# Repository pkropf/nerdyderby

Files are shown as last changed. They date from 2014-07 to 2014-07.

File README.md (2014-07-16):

Nerdy Derby Race Track
======================

This instance of the Nerdy Derby Race Track is a derivative of the
Nerdy Derby project as found at http://nerdyderby.com. Their most
excellent work was an inspiration to creating this one.

As stated on the Nerdy Derby website, "The Nerdy Derby is a no-rules*
miniature car building and racing competition inspired by the Cub
Scouts' Pinewood Derby. With a larger, more undulating track and no
restrictions on the size of the cars or materials participants can
use, the Nerdy Derby rewards creativity, cleverness and ingenuity."

The work represented by these files is intended to help others create
their own tracks and may cause more harm than help. Verify, recheck
and then recheck again everything before you use these files.

Files
-----

The original design came in a reduced scale as a PDF file. The design
was re-implemented in Autodesk Inventor with _nd.iam_ being the
primary assembly file. The _nd-NUMBER.ipt_ and _nd-LETTER.ipt_
represent the individual inside and outside track segments as starting
with the finish line.

The _nd-NUMBER.dxf_ and _nd-LETTER.dxf_ files are the faces of track
segments needed by VCarve Pro to setup the tool path for a ShopBot
Alpha to cut the segments from 3/4" plywood.

The _nd-NUMBER*.crv_ and _nd-LETTER*.crv_ files are the VCarve Pro
files used to generate the _nd-NUMBER*.sbp_ and _nd-LETTER*.sbp_
ShopBot files.

The ShopBot files may or may not work for you. Ensure that you've
verified them before starting them on a ShopBot. If needed, there
should be enough detail in the other files to create the needed
ShopBot files for your installation.

The _track*.skp_ files were an early attempt to create the track
segments using SketchUp. But since Sketchup's circles and curves are
segmented lines, this effort was abandonded and Inventor was used
instead.

Build Time
----------

The curved segments for the track were cut out on a ShopBot Alpha
useing 3 pieces of 3/4" plywood. This work took approximately 8 hours
of ShopBot time.

The straight segments were cut out on a table saw using 2 pieces of
3/4" plywood along with the left over piece from the curvd
segments. This was approximately 4 hours of work.

Glue up of the segments took approximately 5 hours. First assembly
took an additional hour. Standing the track took another 2 hours.

There's another 2 or 3 hours used to buy supplies, transport
materials, etc.

The design work consumed on the order of 6 hours.

Notes
-----

  * Cutting the straight segments on a tablesaw saved ShopBot time but
    cost sanding time since the cuts were not a precise as would have
    been on the ShopBot.

  * The segments should have been numbered / lettered and a toolpath
    created to carve the numbers / letters into the segments on the
    ShopBot. By not doing this, some amount of time was used to just
    organize the segments so that the correct ones were glued
    together.

  * Don't forget to zero the z axis. The ShopBot doesn't know and will
    happily carve into your material and possibly break bits and
    parts.

  * In VCarve Pro, set up 2 tabs per piece, especially for longer pieces.

  * The default 1/8" tab is too shallow for plywood. Use 1/4" tabs.

  * Ensure that the tabs aren't being cut by a previous or following pass.

  * Make sure tabs aren't connected to other pieces that are cut out.

  * The ShopBot files were exported from VCarve Pro as Shopbot alpha w/ speed.

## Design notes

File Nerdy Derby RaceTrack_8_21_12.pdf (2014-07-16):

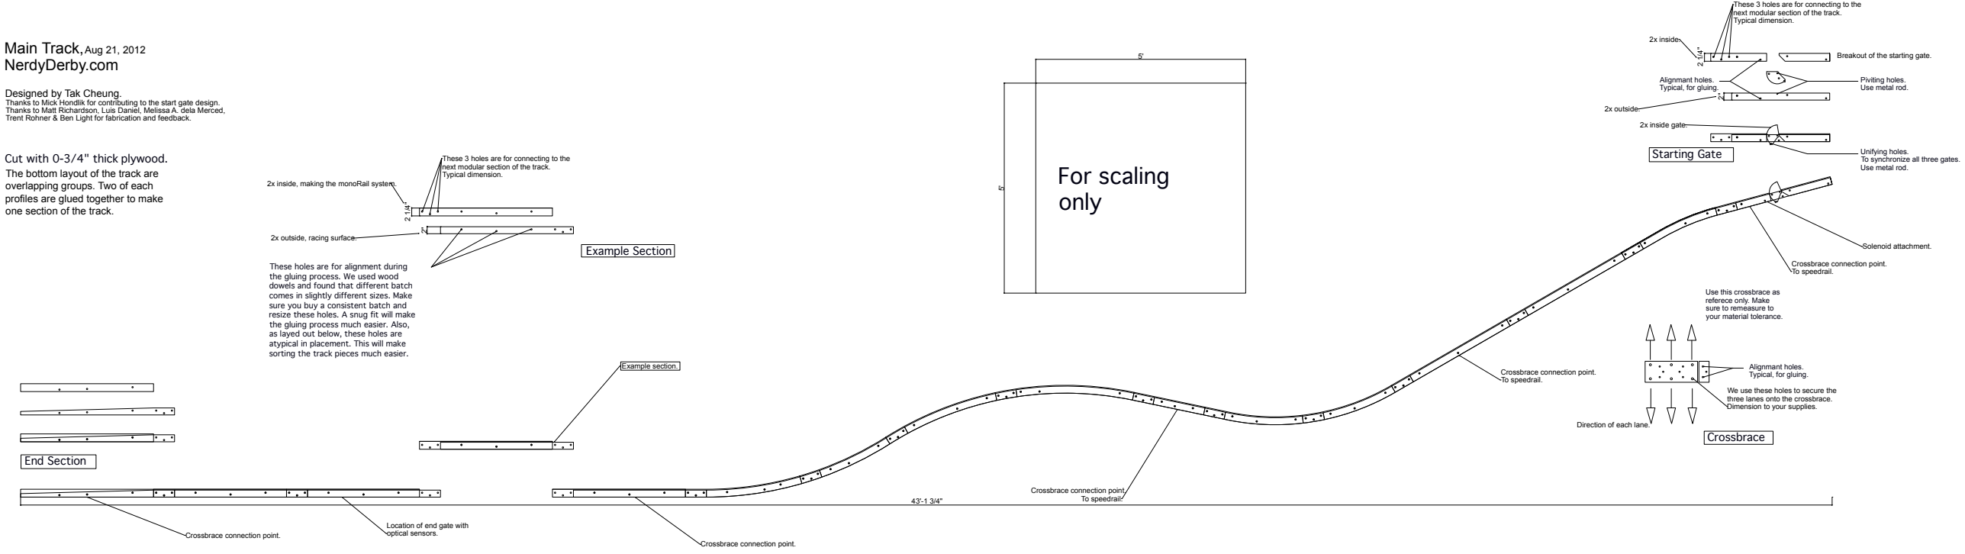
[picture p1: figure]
Main Track, Aug 21, 2012 NerdyDerby.com; Example section.; 2x inside, making the monoRail system.; 2x outside, racing surface.; These 3 holes are for connecting to the next modular section of the track. Typical dimension.; These holes are for alignment during the gluing process. We used wood dowels and found that different batch comes in slightly different sizes. Make sure you buy a consistent batch and the gluing process much easier. Also, as layed out below, these holes are atypical in placement. This will make sorting the track pieces much easier.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

## resize these holes. A snug fit will make

These 3 holes are for connecting to the

Thanks to Mick Hondlik for contributing to the start gate design. Thanks to Matt Richardson, Luis Daniel, Melissa A. dela Merced, Trent Rohner & Ben Light for fabrication and feedback.

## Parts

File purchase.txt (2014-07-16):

dowel for axels, 1 1/4"
balsa wood for body, 1 1/4 x 1 3/4 x 7

mcmaster $157.62

need

rasps?
graph paper

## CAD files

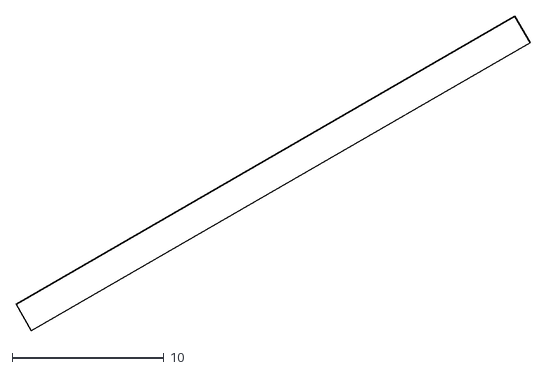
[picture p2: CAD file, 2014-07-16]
nd-n.dxf
33.9 x 20.7

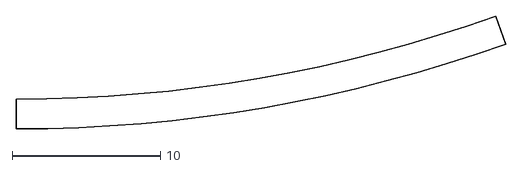
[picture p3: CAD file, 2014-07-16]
nd-f.dxf
33.0 x 7.61

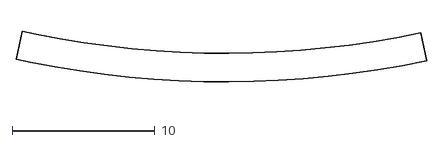
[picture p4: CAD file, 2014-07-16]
nd-k.dxf
28.7 x 4.04

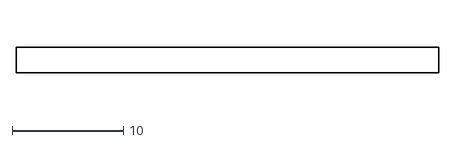
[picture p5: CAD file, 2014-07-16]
nd-5.dxf
38.0 x 2.25

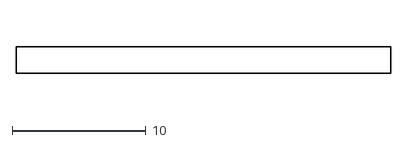
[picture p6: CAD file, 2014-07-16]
nd-p.dxf
28.0 x 2.00

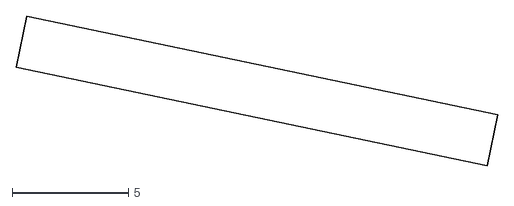
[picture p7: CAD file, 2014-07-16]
nd-10.dxf
20.8 x 6.44

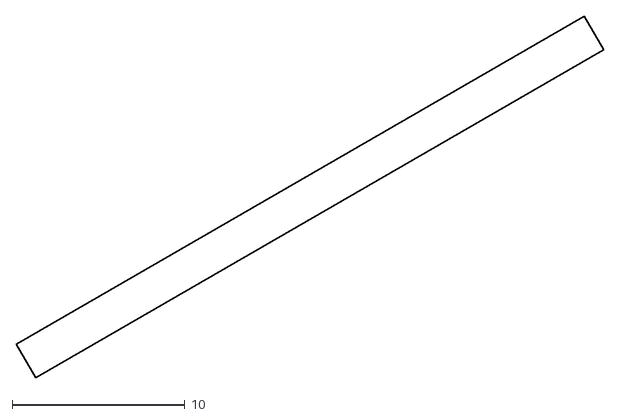
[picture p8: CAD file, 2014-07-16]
nd-14.dxf
34.0 x 20.9

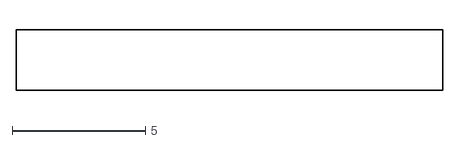
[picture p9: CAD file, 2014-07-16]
nd-16.dxf
16.0 x 2.25

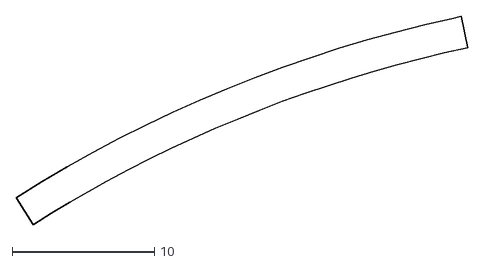
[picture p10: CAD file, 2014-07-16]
nd-8.dxf
31.8 x 14.6

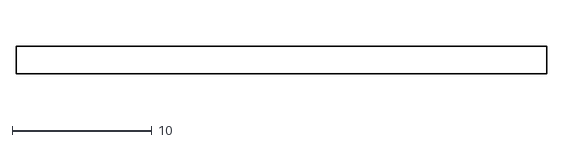
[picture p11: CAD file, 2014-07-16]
nd-b.dxf
38.0 x 2.00

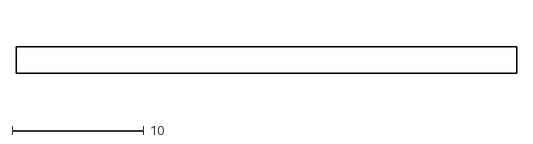
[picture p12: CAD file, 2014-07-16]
nd-d.dxf
38.0 x 2.00

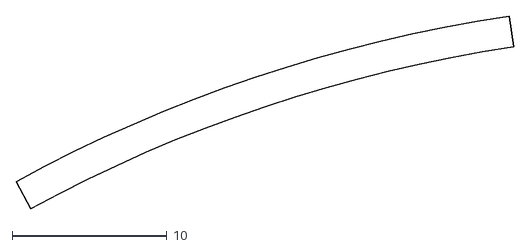
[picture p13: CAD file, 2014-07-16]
nd-h.dxf
32.1 x 12.4

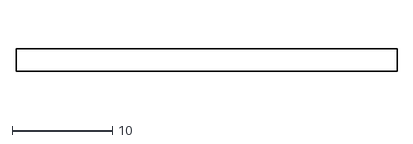
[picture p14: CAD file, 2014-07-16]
nd-2.dxf
38.0 x 2.25

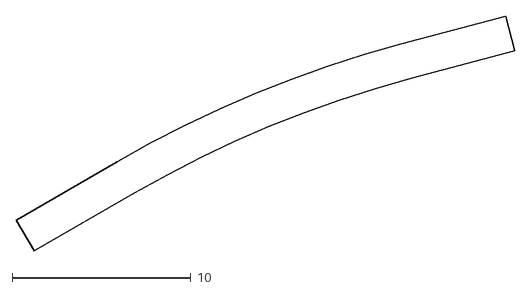
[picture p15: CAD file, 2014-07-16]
nd-o.dxf
27.9 x 13.1

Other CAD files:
Nerdy Derby RaceTrack_8_21_12.dwg
Nerdy Derby RaceTrack Pieces.dwg
nd-4.dxf
nd-11.dxf
nd-1.dxf
nd-1.ipt
nd-10.ipt
nd-10_MIR.ipt
nd-11.ipt
nd-11_MIR.ipt
nd-12.dxf
nd-12.ipt
nd-12_MIR.ipt
nd-13.dxf
nd-13.ipt
nd-13_MIR.ipt
nd-14.ipt
nd-14_MIR.ipt
nd-15.dxf
nd-15.ipt
nd-15_MIR.ipt
nd-16.ipt
nd-16_MIR.ipt
nd-17.dxf
nd-17.ipt
nd-17_MIR.ipt
nd-1_MIR.ipt
nd-2.ipt
nd-2_MIR.ipt
nd-3.dxf
nd-3.ipt
nd-3_MIR.ipt
nd-4.ipt
nd-4_MIR.ipt
nd-5.ipt
nd-5_MIR.ipt
nd-6.dxf
nd-6.ipt
nd-6_MIR.ipt
nd-7.dxf
nd-7.ipt
nd-7_MIR.ipt
nd-8.ipt
nd-8_MIR.ipt
nd-9.dxf
nd-9.ipt
nd-9_MIR.ipt
nd-a.dxf
nd-a.ipt
nd-a_MIR.ipt
nd-a_MIR1.ipt
nd-b.ipt
nd-b_MIR.ipt
nd-c.dxf
nd-c.ipt
nd-c_MIR.ipt
nd-d.ipt
nd-d_MIR.ipt
nd-e.dxf
nd-e.ipt
nd-e_MIR.ipt
nd-f.ipt
nd-f_MIR.ipt
nd-g.dxf
nd-g.ipt
nd-g_MIR.ipt
nd-gate.dxf
nd-gate.ipt
nd-h.ipt
nd-h_MIR.ipt
nd-i.dxf
nd-i.ipt
nd-i_MIR.ipt
nd-j.dxf
nd-j.ipt
nd-j_MIR.ipt
nd-k.ipt
nd-k_MIR.ipt
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

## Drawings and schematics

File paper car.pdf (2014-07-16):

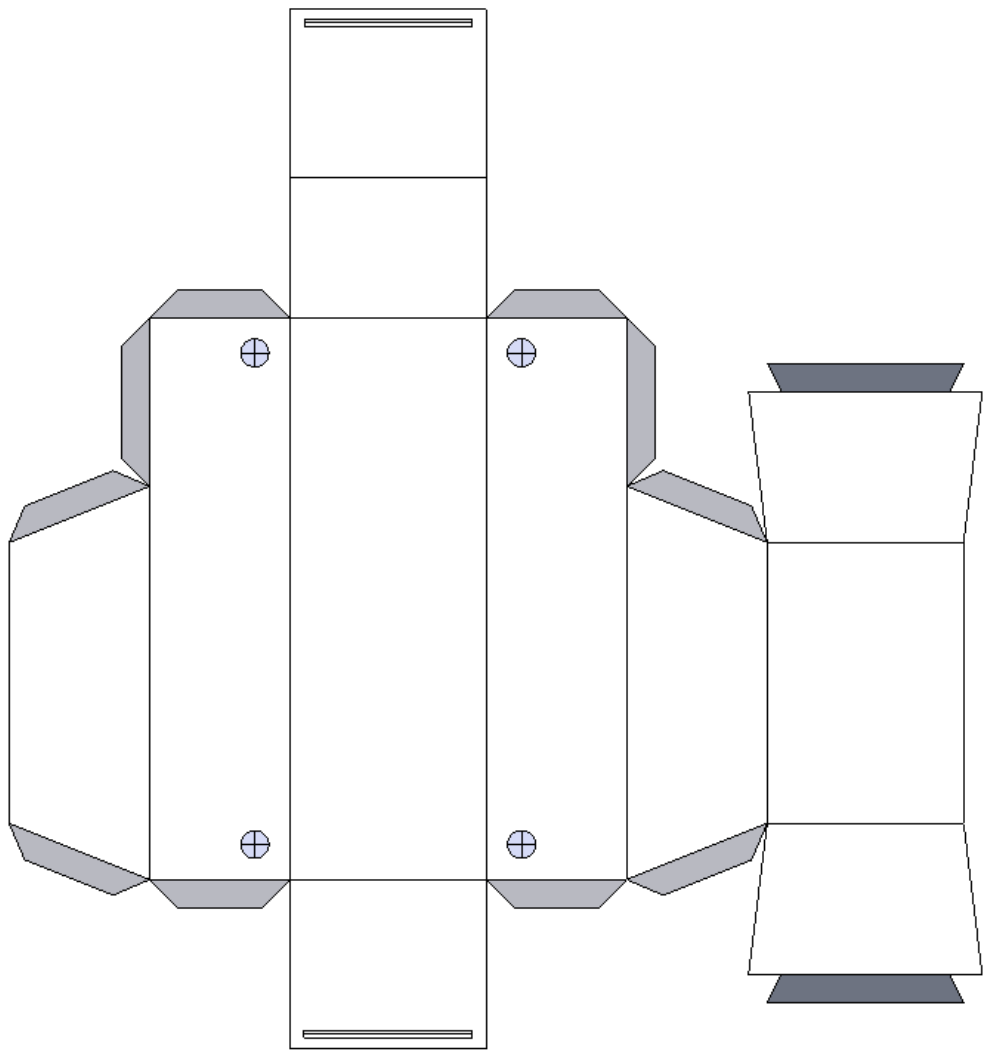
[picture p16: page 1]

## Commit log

2012-11-23 initial checkin.
    [Nerdy Derby RaceTrack_8_21_12.dwg, track.skp]
2012-11-23 moved the various sections to their own work files. added supports and stands to the full track.
    [track divider.skp, track inside.skp, track outside.skp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]
2014-07-02 added pieces file.
    [Nerdy Derby RaceTrack Pieces.dwg]
2014-07-02 created inventor parts and assembly for the track.
    [nd-1.ipt, nd-10.ipt, nd-10_MIR.ipt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]
2014-07-02 added export of faces for use in vcarvepro.
    [nd-1.dxf, nd-10.dxf, nd-11.dxf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]
2014-07-03 updated cars.
    [paper car.skp, track.skp]
